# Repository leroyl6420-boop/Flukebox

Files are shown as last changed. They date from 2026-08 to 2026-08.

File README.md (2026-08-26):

# Flukebox
A portable, off-grid, open-source MP3 player! Supports Bluetooth Classic and analog headphones. 

# Overview
The Flukebox V1.0 is yet another MP3 player for the Hack Clubber who is sick of tired of paying for Spotify Premium. With its ESP32-WROOM-32E-N8 and PCM5102 DAC module, the Flukebox can be used with either Bluetooth or wired analog headphones. With the recommended 8GB Micro SD card, it can hold more than 50 hours of 320 kbps of MP3 music. The 1100 mah battery keeps the Flukebox running for up to 7 hours, and its TP4056 charger supporting USB-C will have a full charge in as little as 90 minutes. Best of all, the Flukebox gives you all that performance in a 90x60 mm case that is only 20mm thick.

# PCB Design

The Flukebox V1.0 uses a two-layer PCB to house all its MCU's, modules, resistors and capacitors. Due to my inexperience in soldering, I didn't feel ready to order a bunch of bare components off Digikey or LCSC and solder them all together. Instead, I ordered modules for the things I needed the Flukebox to do, and am planning to solder them right onto the PCB using cut pin headers or solid wire. I will probably ditch this strategy in a future version, but it'll do for now. At least it makes the schematic and PCB design easier.

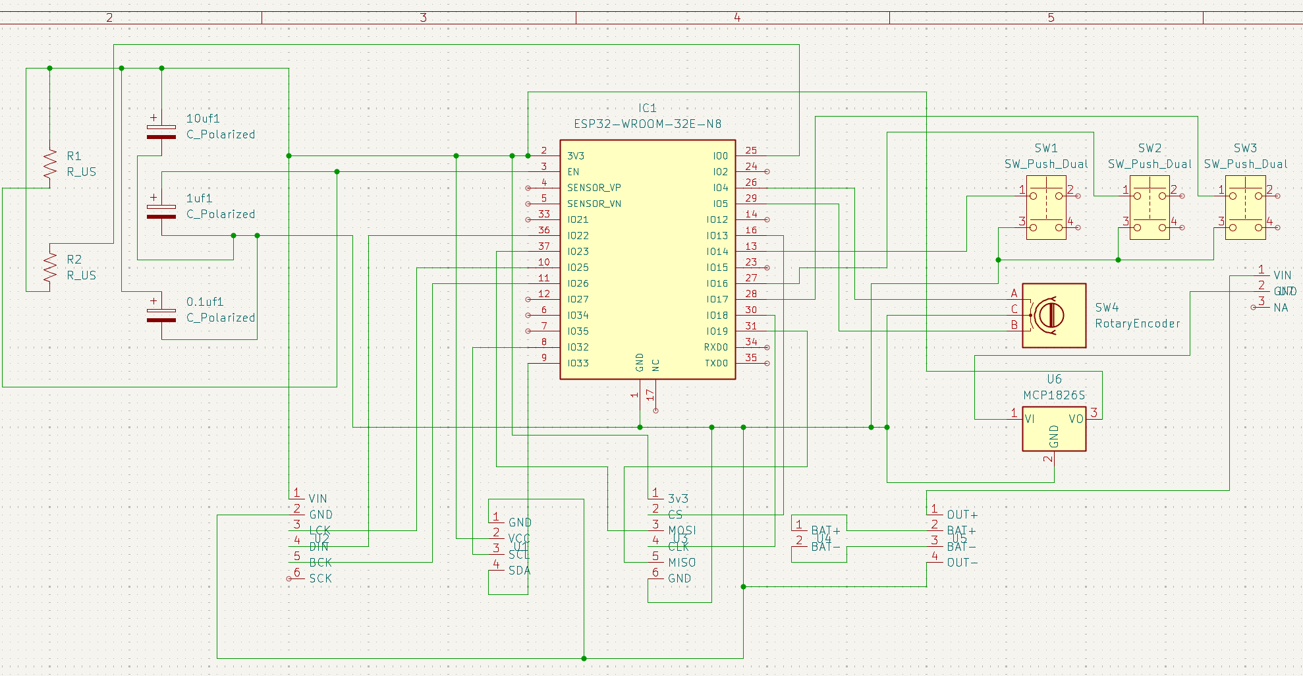
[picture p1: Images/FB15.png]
An image of the Flukebox's PCB's schematic

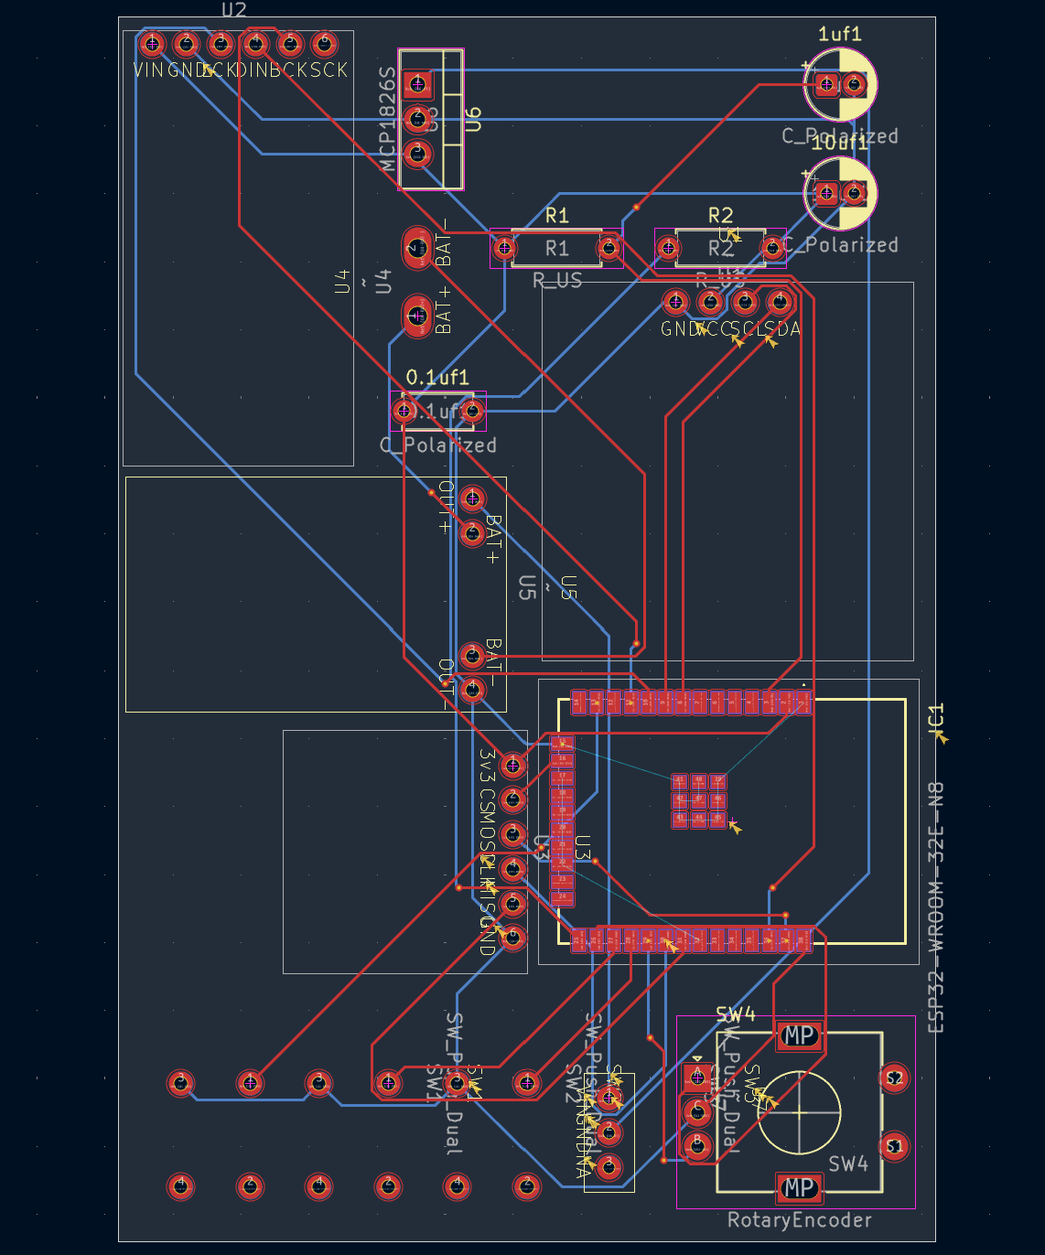
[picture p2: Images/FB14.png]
An image of the Flukebox's PCB's design


# CAD

The CAD for the Flukebox was pretty simple. I gave the PCB a 0.2 mm clearance on both sides, made a case, cut some holes for the USB-C charger and the analog headphone jack, made a lid, cut holes for the OLED, buttons, power switch, and EC11, and that was pretty much it. I have a lot of experience in these things. What was more fun was making an assembly of the finished PCB using KiCad's STEP model and models of the components I'm using I found online. I think it looks super cool! It's just a shame how the pads for the ESP-WROOM-32 didn't render, forcing me to take measurements from KiCad. Oh, well.

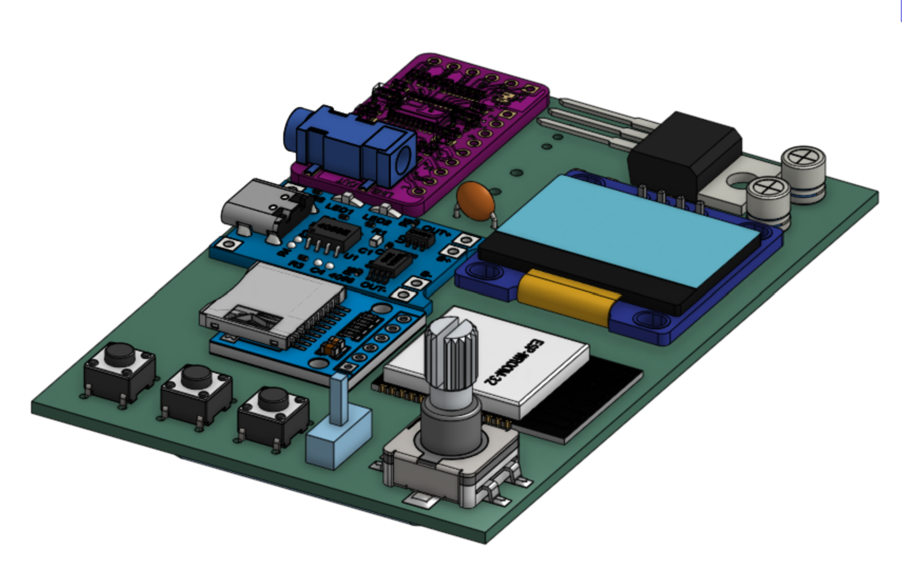
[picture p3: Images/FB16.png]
An image of the Flukebox V1.0 PCB assembly

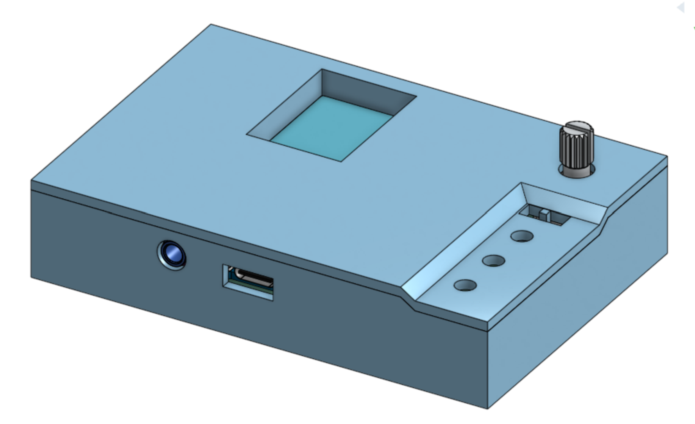
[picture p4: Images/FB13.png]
An image of the full Flukebox V1.0 assembly


# BOM

Here are all the components you'll need for the Flukebox V1.0:

| Part | Quantity | Cost | Link |
|---|---:|---:|---|
| Flukebox V1.0 PCB | 1 | $6.14 | [PCBWay](https://www.pcbway.com/) |
| 1100mAh 3.7V LiPo Battery | 1 | $6.15 | [Amazon](https://www.amazon.com/EEMB-1100mAh-Battery-Rechargeable-Connector/dp/B08VRYS8FT) |
| Micro SD Reader | 1 | $5.99 | [Amazon](https://www.amazon.com/Adapter-Reader-Interface-Arduino-Raspberry/dp/B0H493ZTBM) |
| 128x64 OLED | 1 | $3.00 | [Amazon](https://www.amazon.com/Hosyond-Display-Self-Luminous-Compatible-Raspberry/dp/B09T6SJBV5) |
| TP4056 Charging Module | 1 | $5.99 | [Amazon](https://www.amazon.com/HiLetgo-Lithium-Charging-Protection-Functions/dp/B07PKND8KG) |
| EC11 Rotary Encoder | 1 | $3.00 | [Amazon](https://www.amazon.com/WWZMDiB-Encoder-Digital-Potentiometer-Arduino/dp/B0C6Q67V97) |
| 6x6mm 4-pin Push Buttons | 3 | $0.15 | [Amazon](https://www.amazon.com/QTEATAK-Momentary-Tactile-Button-Switch/dp/B07VSNN9S2) |
| PCM5102 DAC Module | 1 | $8.88 | [Amazon](https://www.amazon.com/PCM5102-PCM5102A-Digital-Converter-Raspberry/dp/B0DNW32Y46) |
| ESPRESSIF ESP32-WROOM-32E-N8 | 1 | $5.43 | [DigiKey](https://www.digikey.com/en/products/detail/espressif-systems/ESP32-WROOM-32E-N8/13159522) |
| Slide Switch | 1 | $0.30 | [Amazon](https://www.amazon.com/Position-Breadboard-Electronic-Miniature-SlideSwitch/dp/B09R3XLVVS) |
| MCP1826S-3302E/AB | 1 | $1.32 | [DigiKey](https://www.digikey.com/en/products/detail/microchip-technology/MCP1826S-3302E-AB/1635996) |
| 0.1uF / 100nF Capacitor | 1 | $0.07 | [Amazon](https://www.amazon.com/Cermant-Ceramic-Capacitor-Electronic-Components/dp/B09XV2H8JQ) |
| 1uF 5x11 Capacitor | 1 | $0.40 | [Amazon](https://www.amazon.com/ALLECIN-Electrolytic-Capacitor-0-2x0-43in-Capacitors/dp/B0CMQC587X) |
| 10uF 5x11 Capacitor | 1 | $0.40 | [Amazon](https://www.amazon.com/ALLECIN-Electrolytic-Capacitor-0-2x0-43in-Capacitors/dp/B0CMQ8FNQL) |
| 10kΩ Resistors | 2 | $0.12 | [Amazon](https://www.amazon.com/EDGELEC-Resistor-Tolerance-Multiple-Resistance/dp/B07QJB31M7) |
| 8GB Micro SD Card *(recommended)* | 1 | $19.99 | [Amazon](https://www.amazon.com/Sandisk-Flash-Memory-Card-SDSDQM-008G-B35/dp/B001D0ROGO) |
| **Total** |  | **$67.33** | |

Of course, you'll also need lead, a soldering iron, and a 3D printer w/filament to print the case and the lid out. Those prices will vary. However, when you don't count those miscellaneous prices, the Flukebox V1.0 will run you $67.33, pre-taxes! That's pretty good!

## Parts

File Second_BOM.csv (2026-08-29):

Part | Quantity | Cost | Link
1100 mah 3.7v Lipo Battery | 1 | $8 | https://www.amazon.com/EEMB-1100mAh-Battery-Rechargeable-Connector/dp/B08VRYS8FT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
0.1uf 100nf Capacitor | 1 | $6.99 | https://www.amazon.com/Cermant-Ceramic-Capacitor-Electronic-Components/dp/B09XV2H8JQ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
1uf 5x11 Capacitor | 1 | $5.99 | https://www.amazon.com/ALLECIN-Electrolytic-Capacitor-0-2x0-43in-Capacitors/dp/B0CMQC587X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
8GB Micro SD Card (recommended) | 1 | $7.00 | https://www.amazon.com/Sandisk-Flash-Memory-Card-SDSDQM-008G-B35/dp/B001D0ROGO?s=electronics
Total(W/Tax) |  | $31

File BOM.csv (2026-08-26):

Part | Quantity | Cost | Link
Flukebox V1.0 PCB | 1 | $6.14 | https://www.pcbway.com/
1100 mah 3.7v Lipo Battery | 1 | $6.15 | https://www.amazon.com/EEMB-1100mAh-Battery-Rechargeable-Connector/dp/B08VRYS8FT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
Micro SD Reader | 1 | $5.99 | https://www.amazon.com/Adapter-Reader-Interface-Arduino-Raspberry/dp/B0H493ZTBM
128x64 OLED | 1 | $3.00 | https://www.amazon.com/Hosyond-Display-Self-Luminous-Compatible-Raspberry/dp/B09T6SJBV5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
TP4056 Charging Module | 1 | $5.99 | https://www.amazon.com/HiLetgo-Lithium-Charging-Protection-Functions/dp/B07PKND8KG
EC11 Rotary Encoder | 1 | $3.00 | https://www.amazon.com/WWZMDiB-Encoder-Digital-Potentiometer-Arduino/dp/B0C6Q67V97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
6x6mm 4-pin Push Buttons | 3 | $0.15 | https://www.amazon.com/QTEATAK-Momentary-Tactile-Button-Switch/dp/B07VSNN9S2?sp_csd=d2lkZ2V0TmFtZT1zcF9hdGY
PCM5102 DAC Module | 1 | $8.88 | https://www.amazon.com/PCM5102-PCM5102A-Digital-Converter-Raspberry/dp/B0DNW32Y46
ESPRESSIF ESP32-WROOM-32E-N8 | 1 | $5.43 | https://www.digikey.com/en/products/detail/espressif-systems/ESP32-WROOM-32E-N8/13159522
Slide Switch | 1 | $0.30 | https://www.amazon.com/Position-Breadboard-Electronic-Miniature-SlideSwitch/dp/B09R3XLVVS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
MCP1826S-3302E/AB | 1 | $1.32 | https://www.digikey.com/en/products/detail/microchip-technology/MCP1826S-3302E-AB/1635996
0.1uf 100nf Capacitor | 1 | $0.07 | https://www.amazon.com/Cermant-Ceramic-Capacitor-Electronic-Components/dp/B09XV2H8JQ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
1uf 5x11 Capacitor | 1 | $0.40 | https://www.amazon.com/ALLECIN-Electrolytic-Capacitor-0-2x0-43in-Capacitors/dp/B0CMQC587X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
10uf 5x11 Capacitor | 1 | $0.40 | https://www.amazon.com/ALLECIN-Electrolytic-Capacitor-0-2x0-43in-Capacitors/dp/B0CMQ8FNQL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
10k ohm Resistors | 2 | $0.12 | https://www.amazon.com/EDGELEC-Resistor-Tolerance-Multiple-Resistance/dp/B07QJB31M7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
8GB Micro SD Card (recommended) | 1 | $19.99 | https://www.amazon.com/Sandisk-Flash-Memory-Card-SDSDQM-008G-B35/dp/B001D0ROGO?s=electronics
Total |  | $67.33

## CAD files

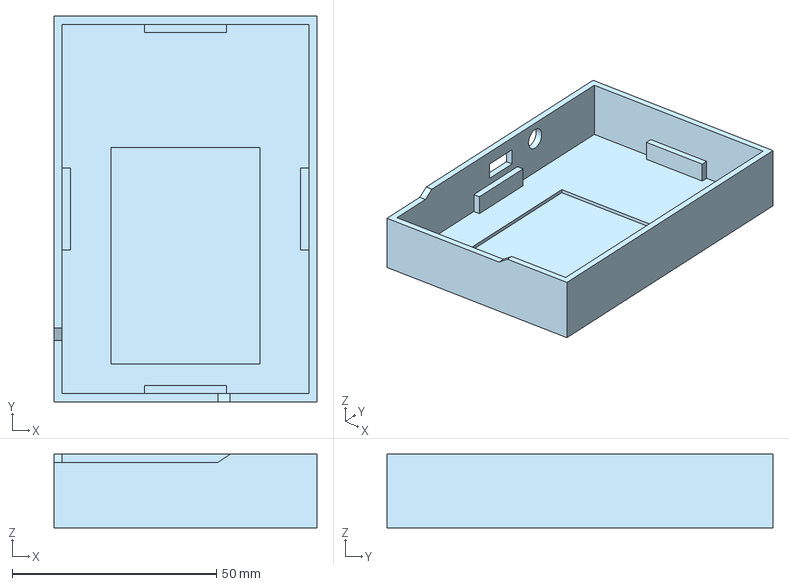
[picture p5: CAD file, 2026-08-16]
STEP Files/Main Case.step
64.4 x 94.4 x 18.0 mm

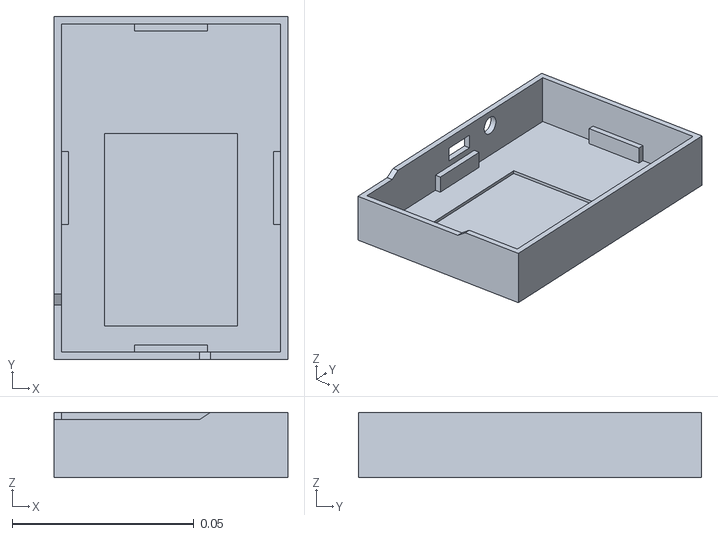
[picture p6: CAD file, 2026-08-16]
Production/Main Case.stl
0.0644 x 0.0944 x 0.018

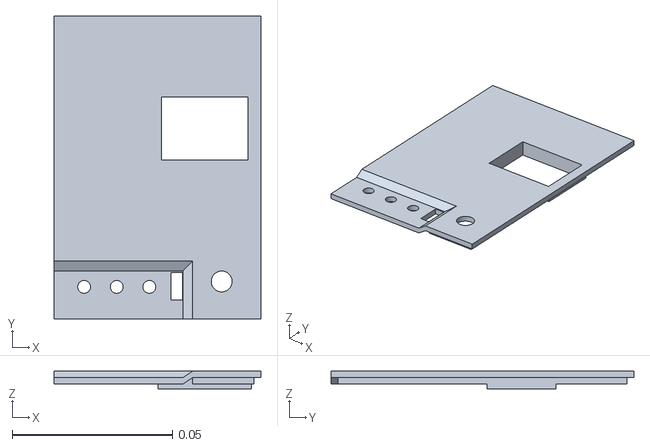
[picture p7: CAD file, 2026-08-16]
Production/Lid.stl
0.0644 x 0.0944 x 0.0055

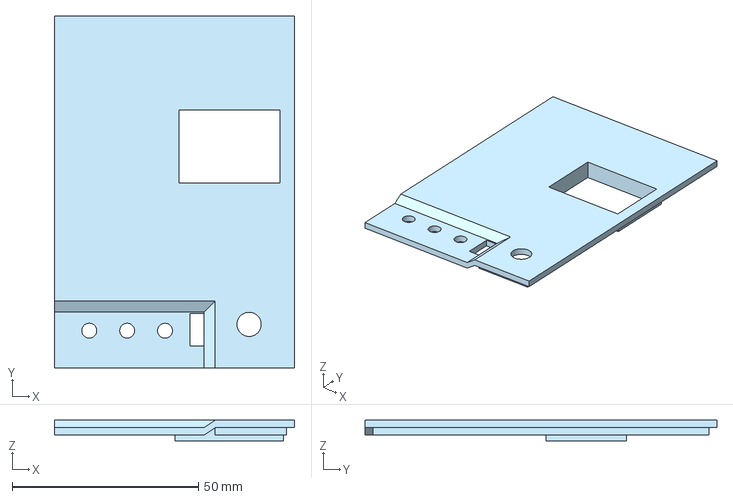
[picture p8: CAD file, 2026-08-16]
STEP Files/Lid.step
64.4 x 94.4 x 5.50 mm

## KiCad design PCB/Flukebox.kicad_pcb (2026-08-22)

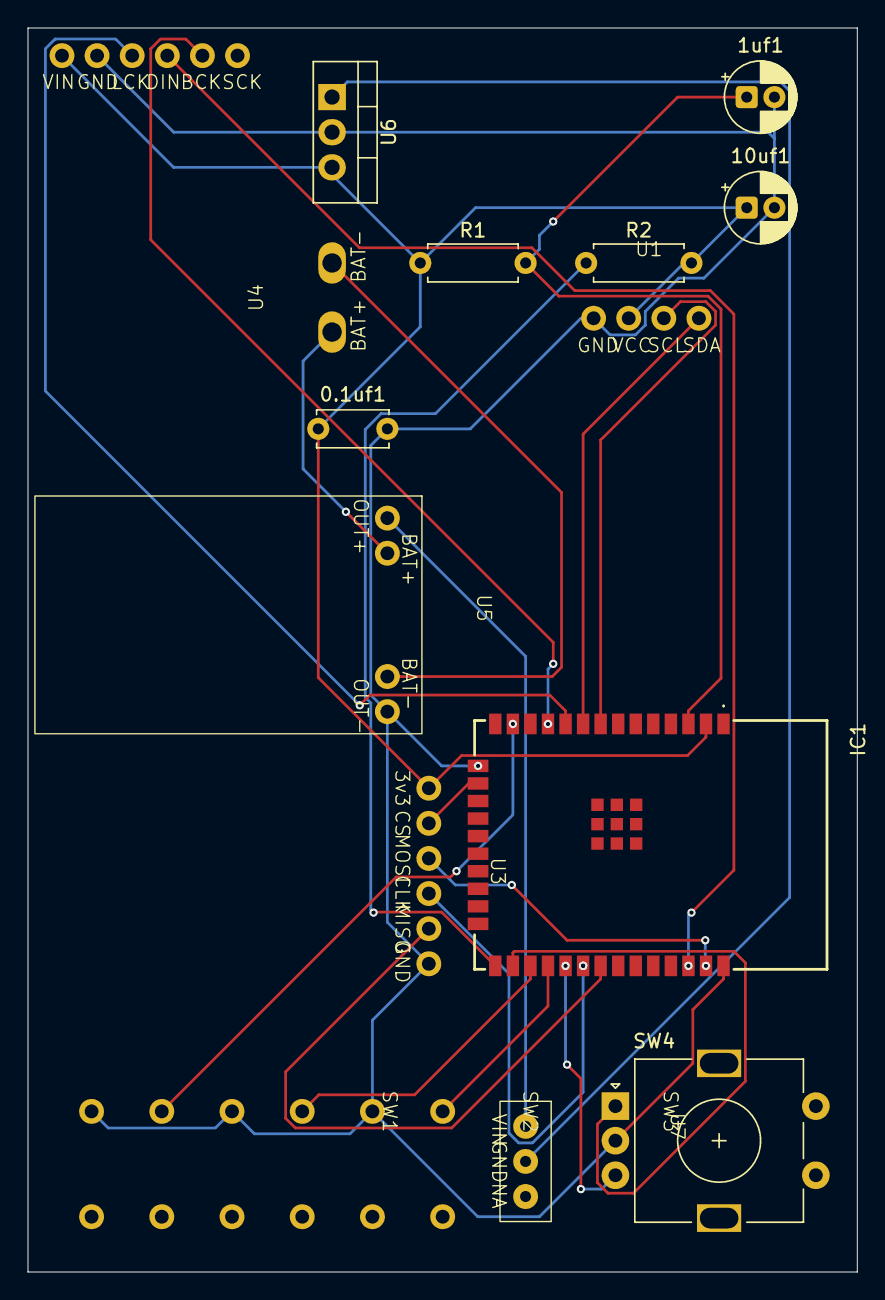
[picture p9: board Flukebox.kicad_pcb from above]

Board: 2 copper layers, 60.0 x 90.0 mm, 17 parts (0 on the bottom side), 23 nets.

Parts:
0.1uf1: C_Polarized; C_Disc_D5.0mm_W2.5mm_P5.00mm
1uf1, 10uf1: C_Polarized; CP_Radial_D5.0mm_P2.00mm
IC1: ESP32-WROOM-32E-N8; ESP32WROOM32EN8
R1, R2: R_US; R_Axial_DIN0207_L6.3mm_D2.5mm_P7.62mm_Horizontal
SW1, SW2, SW3: SW_Push_Dual; Push_Button_4pin
SW4: RotaryEncoder; RotaryEncoder_Alps_EC11E-Switch_Vertical_H20mm
U1: 128x64_OLED_4pin
U2: DAC_Module_6pin
U3: Micro_SD_Reader_6pin
U4: Spliced_Lipo_Battery
U5: TP4056_Charging_Module_4pin
U6: MCP1826S; TO-220-3_Vertical
U7: Slide_Switch_3pin

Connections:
unnamed: 0.1uf1.1, 10uf1.1, IC1.2 (3V3), R1.1, R2.2, U1.2 (VCC), U2.1 (VIN), U3.1 (3v3), U6.3 (VO)
unnamed: 1uf1.1, IC1.3 (EN), R1.2
unnamed: IC1.25 (IO0), R2.1
unnamed: IC1.26 (IO4), SW4.A
unnamed: IC1.29 (IO5), SW4.B
unnamed: IC1.16 (IO13), U3.2 (CS)
unnamed: IC1.13 (IO14), SW1.1
unnamed: IC1.27 (IO16), SW2.1
unnamed: IC1.28 (IO17), SW3.1
unnamed: IC1.30 (IO18), U3.4 (CLK)
unnamed: IC1.31 (IO19), U3.5 (MISO)
unnamed: IC1.36 (IO22), U2.4 (DIN)
unnamed: IC1.37 (IO23), U3.3 (MOSI)
unnamed: IC1.10 (IO25), U2.3 (LCK)
unnamed: IC1.11 (IO26), U2.5 (BCK)
unnamed: IC1.8 (IO32), U1.3 (SCL)
unnamed: IC1.9 (IO33), U1.4 (SDA)
unnamed: IC1.17 (NC), IC1.18 (NC), IC1.19 (NC), IC1.20 (NC), IC1.21 (NC), IC1.22 (NC), IC1.32 (NC)
unnamed: 0.1uf1.2, 1uf1.2, 10uf1.2, IC1.1 (GND), IC1.15 (GND), IC1.38 (GND), IC1.39 (GND), IC1.40 (GND), IC1.41 (GND), IC1.42 (GND), IC1.43 (GND), IC1.44 (GND), IC1.45 (GND), IC1.46 (GND), IC1.47 (GND), SW1.3, SW2.3, SW3.3, SW4.C, U1.1 (GND), U2.2 (GND), U3.6 (GND), U5.4 (OUT-), U6.2 (GND)
unnamed: U4.1 (BAT+), U5.2 (BAT+)
unnamed: U4.2 (BAT-), U5.3 (BAT-)
unnamed: U5.1 (OUT+), U7.1 (VIN)
unnamed: U6.1 (VI), U7.2 (GND)

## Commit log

2026-08-16 Fix image link for Flukebox PCB design in README
2026-08-16 Update BOM section to link to BOM.csv
    Removed detailed BOM list and linked to BOM.csv instead.
2026-08-16 Update BOM link to relative path
2026-08-16 Refactor BOM entries for Flukebox V1.0
    Updated the Bill of Materials (BOM) for Flukebox V1.0 to remove redundant entries and simplify the list.
2026-08-26 Add shipping cost to BOM
    Updated BOM.csv to include shipping cost.
    [BOM.csv]
